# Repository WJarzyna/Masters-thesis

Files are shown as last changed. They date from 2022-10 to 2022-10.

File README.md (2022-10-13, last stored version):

# Praca-inzynierska
Sterownik silnika synchronicznego ze zmiennym momentem magnetycznym wirnika

Poniższe repozytorium zawiera materiały dotyczące budowy sterownika silnika. Docelowo silnik ma powstać na bazie zmodyfikowanego alternatora Magneti Marelli 14V/55A i udostępniać następujące metody sterowania:
- z wykorzystaniem czujników Halla
- z wykorzystaniem sygnału BEMF
- przez pomiar prądów fazowych

Założenia projektowe sterownika:
- budowa modularna - płyta główna + 3 płyty z półmostkami
- separacja galwaniczna części sterowania i mocy
- sterowanie poprzez mikrokontroler Raspberry Pi RP2040

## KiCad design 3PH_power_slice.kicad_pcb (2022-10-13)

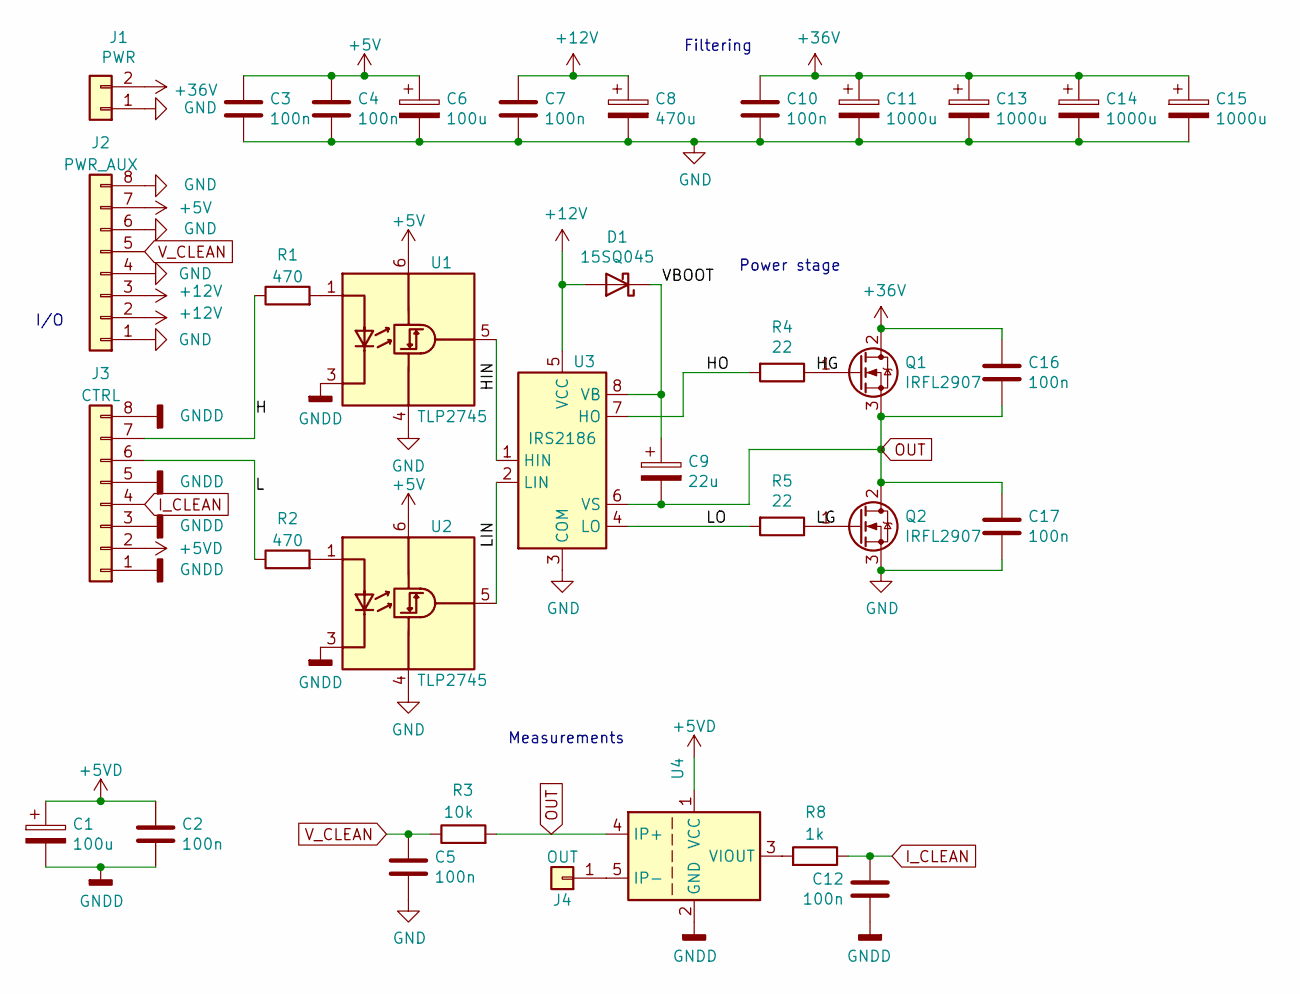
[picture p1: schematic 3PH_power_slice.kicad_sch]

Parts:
C1, C6: 100u; CP_Radial_D5.0mm_P2.50mm
C2, C3, C4, C5, C7, C10, C12, C16, C17: 100n; C_0805_2012Metric
C8: 470u; CP_Radial_D10.0mm_P5.00mm
C9: 22u; CP_Radial_D5.0mm_P2.50mm
C11, C13, C14, C15: 1000u; CP_Radial_D12.5mm_P5.00mm
D1: 15SQ045; D_P600_R-6_P12.70mm_Horizontal
J1: PWR; XT90PB
J2: PWR_AUX; PinHeader_1x08_P2.54mm_Vertical
J3: CTRL; PinHeader_1x08_P2.54mm_Vertical
J4: OUT; XT90PB_1Pin
Q1, Q2: IRFL2907; TO-247-3_Vertical
R1, R2: 470; R_0805_2012Metric
R3: 10k; R_0805_2012Metric
R4, R5: 22; R_Axial_DIN0411_L9.9mm_D3.6mm_P12.70mm_Horizontal
R8: 1k; R_0805_2012Metric
U1, U2: TLP2745; SO-5_4.4x3.6mm_P1.27mm
U3: IRS2186; DIP-8_W7.62mm_LongPads
U4: ACS758xCB-100B-PFF; Allegro_CB_PFF

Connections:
+5V: C3.1, C4.1, C6.1, J2.7, U1.6 (VDD), U2.6 (VDD)
+5VD: C1.1, C2.1, J3.2, U4.1 (VCC)
+12V: C7.1, C8.1, D1.2 (A), J2.2, J2.3, U3.5 (VCC)
+36V: C10.1, C11.1, C13.1, C14.1, C15.1, C16.1, J1.2, Q1.2 (D)
/H: J3.7, R1.1
/HG: Q1.1 (G), R4.1
/HIN: U1.5 (VO), U3.1 (HIN)
/HO: R4.2, U3.7 (HO)
/L: J3.6, R2.1
/LG: Q2.1 (G), R5.1
/LIN: U2.5 (VO), U3.2 (LIN)
/LO: R5.2, U3.4 (LO)
/VBOOT: C9.1, D1.1 (K), U3.8 (VB)
GND: C3.2, C4.2, C5.2, C6.2, C7.2, C8.2, C10.2, C11.2, C13.2, C14.2, C15.2, C17.2, J1.1, J2.1, J2.4, J2.6, J2.8, Q2.3 (S), U1.4 (GND), U2.4 (GND), U3.3 (COM)
GNDD: C1.2, C2.2, C12.2, J3.1, J3.3, J3.5, J3.8, U1.3 (K), U2.3 (K), U4.2 (GND)
I_CLEAN: C12.1, J3.4, R8.1
unnamed: J4.1, U4.5 (IP-)
unnamed: R1.2, U1.1 (A)
unnamed: R2.2, U2.1 (A)
unnamed: R8.2, U4.3 (VIOUT)
OUT: C9.2, C16.2, C17.1, Q1.3 (S), Q2.2 (D), R3.2, U3.6 (VS), U4.4 (IP+)
V_CLEAN: C5.1, J2.5, R3.1

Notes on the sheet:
I/O
Filtering
Measurements
Power stage

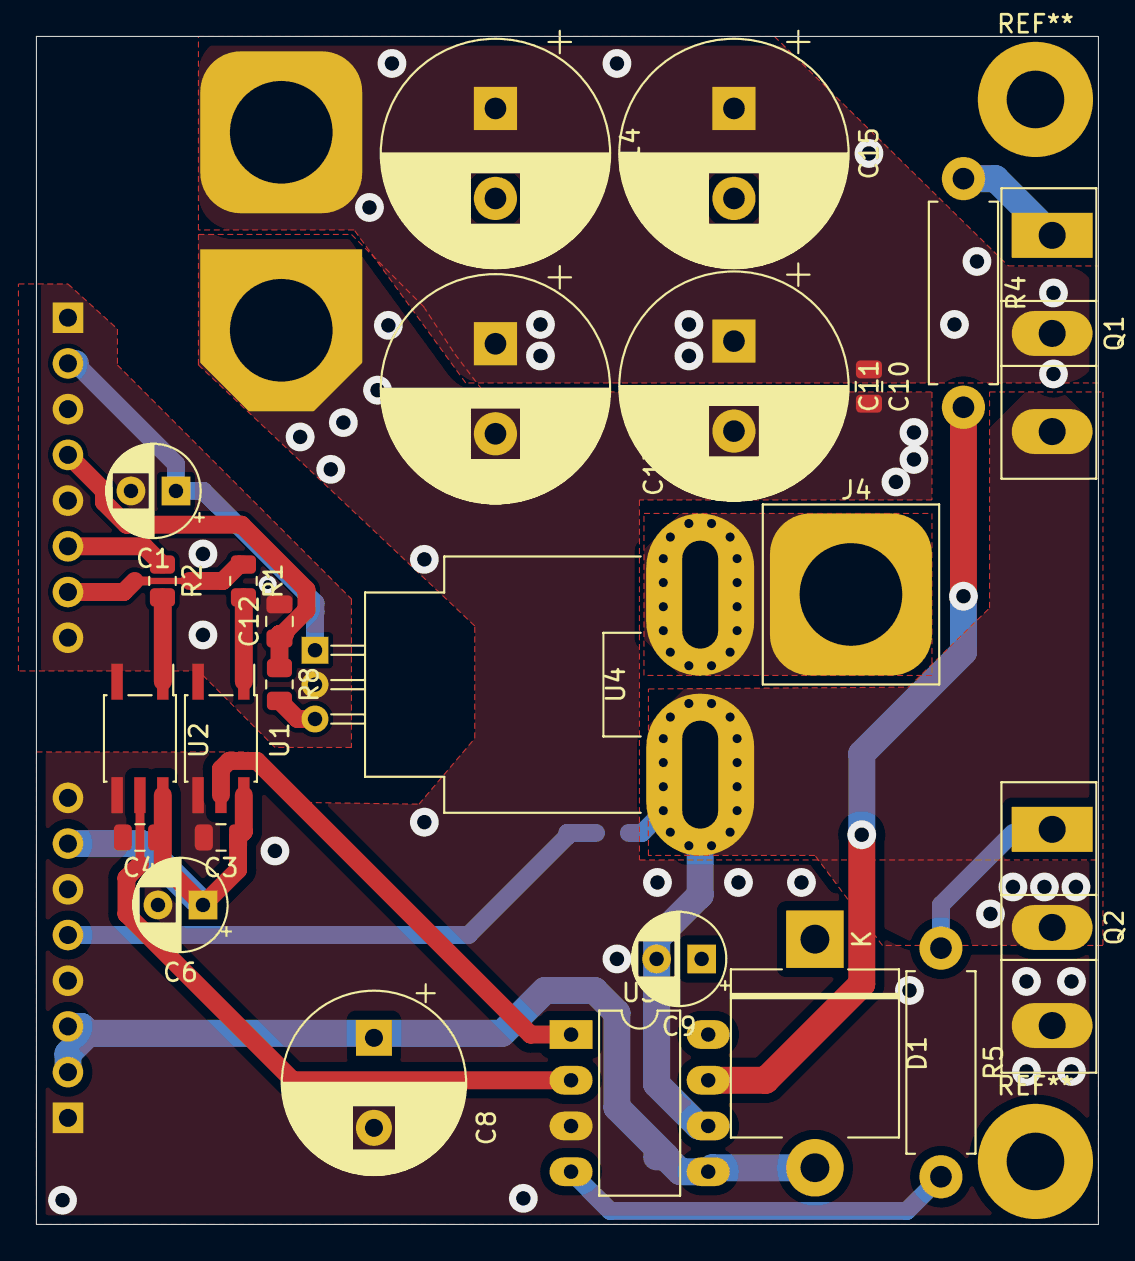
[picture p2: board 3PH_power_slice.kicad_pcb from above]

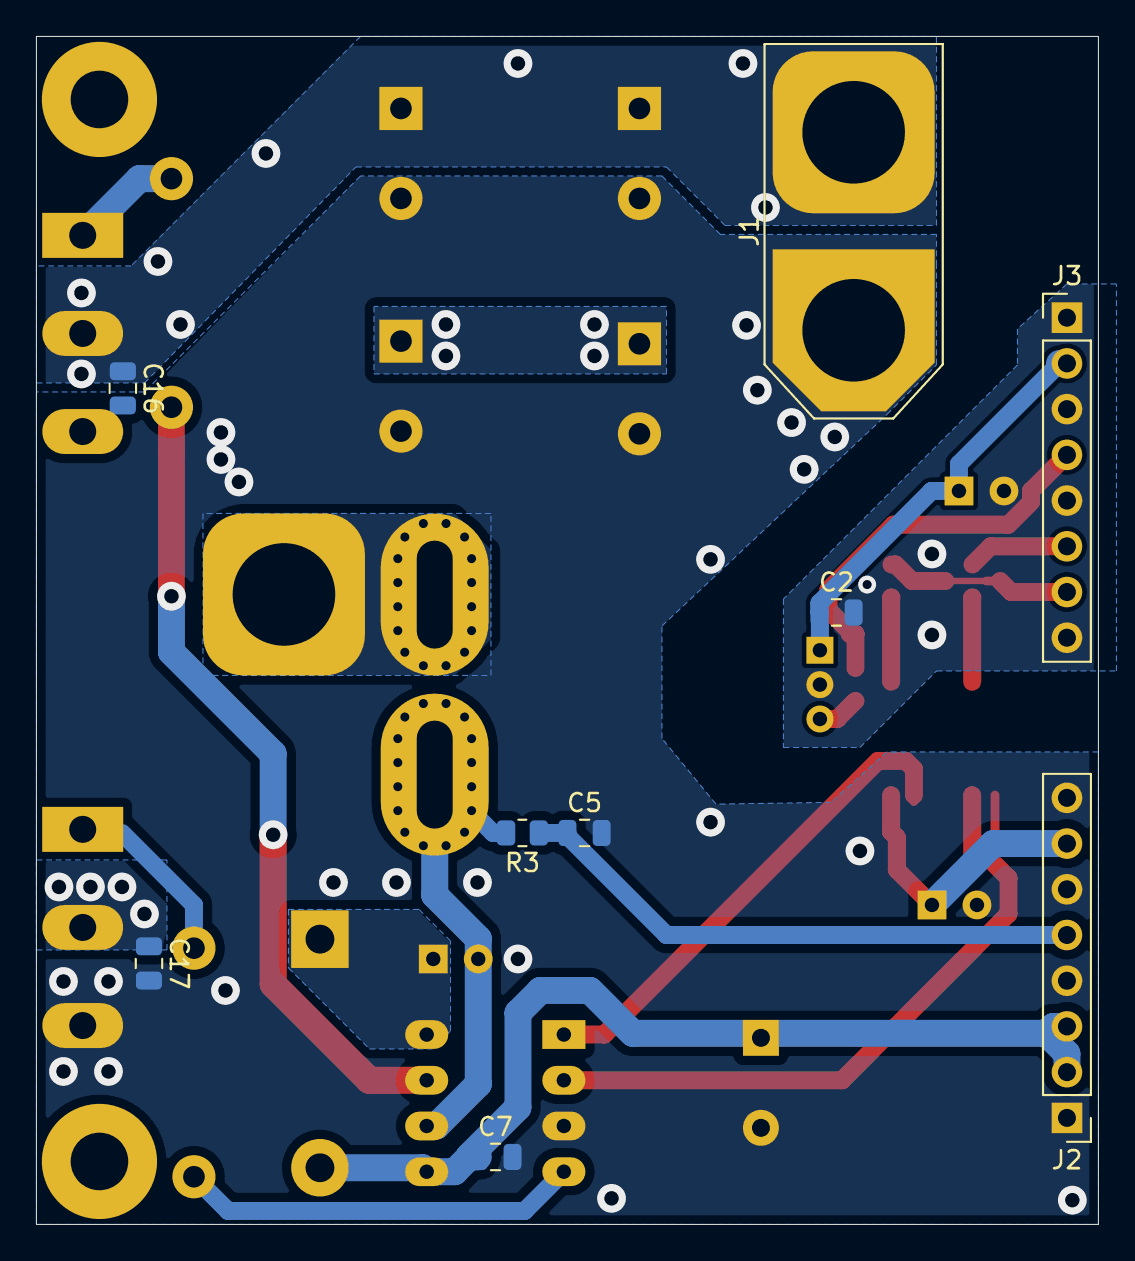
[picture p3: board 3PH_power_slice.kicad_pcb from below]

Board: 2 copper layers, 59.0 x 66.0 mm, 34 parts (9 on the bottom side), 22 nets.

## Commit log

2022-07-31 Dodanie dotychczas zgromadzonych materialow
    [3PH_power_slice.sch]
2022-10-13 Migracja do KiCADa 6, schemat i PCB półmostka
    [3PH_power_slice.kicad_pcb, 3PH_power_slice.kicad_sch]
2022-10-21 porzadki, przeniesienie projektu w IDE, zmiana stopnia mocy
    [3PH_power_slice.sch]
2022-10-31 PID - prototyp. Praca w petli zamknietej, regulacja predkosci
2022-12-01 stable hall with PID
2023-11-29 remote PID tuning
